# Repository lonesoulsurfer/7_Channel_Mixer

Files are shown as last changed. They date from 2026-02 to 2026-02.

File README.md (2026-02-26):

RHIM2508

SITY5105

YouTube - https://youtu.be/h-TxdCl6BcE

Instructables - https://www.instructables.com/7-Channel-Mixer-a-4-Channel-Option/

Here you can find everything you need to make your own 7 Channel Mixer.  This is based on Syntherjacks awesome little 4sum mixer which you can find a link below to.  My modular synth runs off 9/5V so this amp works perfectly for what I need.  You could also power it via traditional Eurorack style powering, you would just have to add a step down converter from the mixer to the 12V power source.

I have also included a Eurorack 4 channel version as well which will fit perfectly into any Eurorack.

https://syntherjack.net/portable-audio-mixer/

7 Channel Mixer - Circuit Explanation

This is a passive-input, op-amp buffered audio mixer built around an NE5532N dual op-amp. 

Here's how it works from input to output:

Input Stage (7 Channels)

* Each of the 7 channels (IN_1 through IN_7) follows the same structure. A 3-pin connector feeds into a 100K potentiometer (VOL_1 through VOL_7) which acts as the individual channel volume control. The wiper of each pot    connects through a 47K resistor to a common summing node. The 47K resistors serve as summing/isolation resistors — they prevent channels from loading each other and set the gain relationship between channels.

Summing & First Op-Amp Stage (IC1A)

* All 7 channel signals meet at the summing node, which connects through a 10µF coupling capacitor (blocking any DC offset) into the non-inverting (+) input of IC1A (the first half of the NE5532N). IC1A is configured as a unity-gain buffer with a 47K feedback resistor, providing a low-impedance version of the mixed signal. VREF is applied to bias the op-amp at the virtual mid-rail since this is a single-supply design.

Second Op-Amp Stage (IC1B) + Master Level

* The output of IC1A feeds into IC1B (the second half of the NE5532N). A 100K master LEVEL potentiometer in the feedback path of IC1B controls the overall output gain/volume. This gives you master level control over the entire mix.

Output Stage

* The output of IC1B passes through another 10µF coupling capacitor (again blocking DC) into an output volume pot and then to the OUT_1 connector.

Power Supply

* The circuit runs off a single +9V supply (PWR_9V connector). A BAT43 Schottky diode provides reverse polarity protection. Two 100µF filter capacitors smooth the supply rail. A resistor divider made of two 47K resistors creates a VREF mid-rail reference (~4.5V), which biases the op-amp stages so they can handle AC audio signals on a single supply. A LED with current-limiting resistor provides a power indicator.

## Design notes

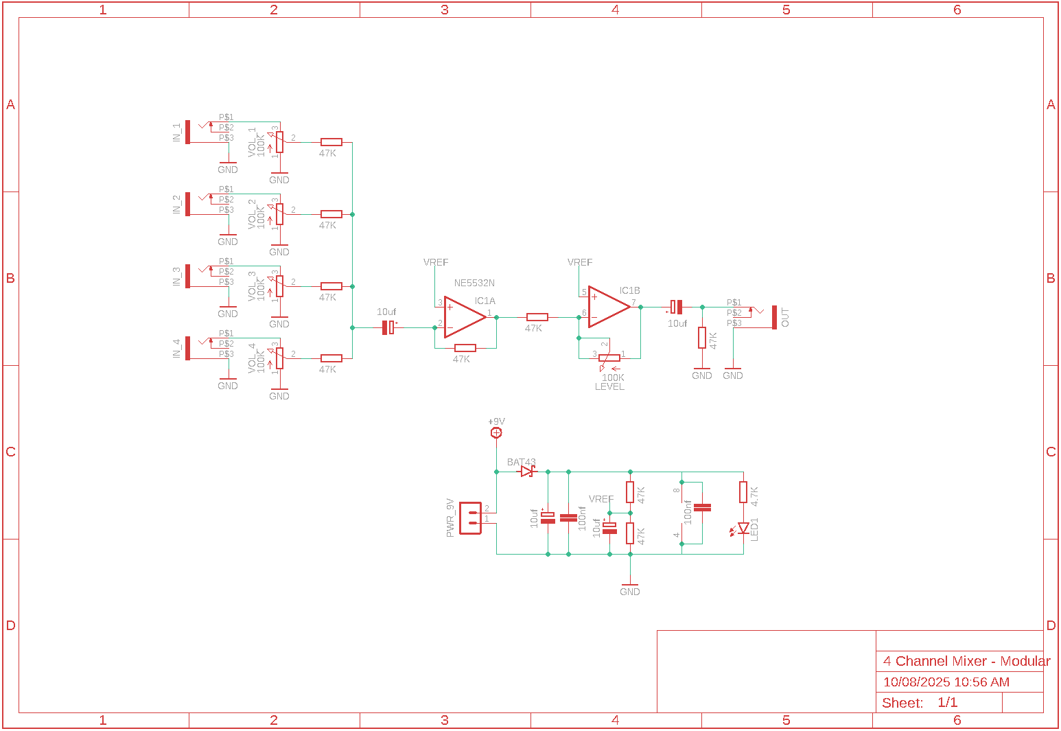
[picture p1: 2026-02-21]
Schematics/4 Channel Mixer - Schematic.png

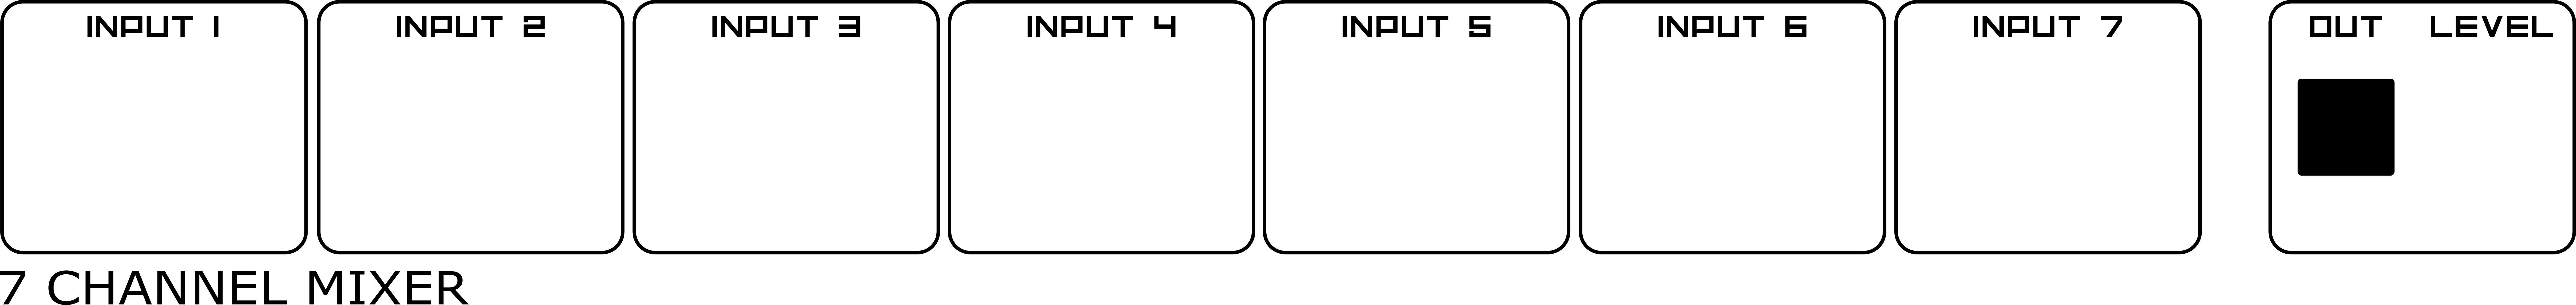
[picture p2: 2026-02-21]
Front_Panel_Design/7_Channel_Mixer_Front_Panel/7 Channel Mixer - Front Panel.png

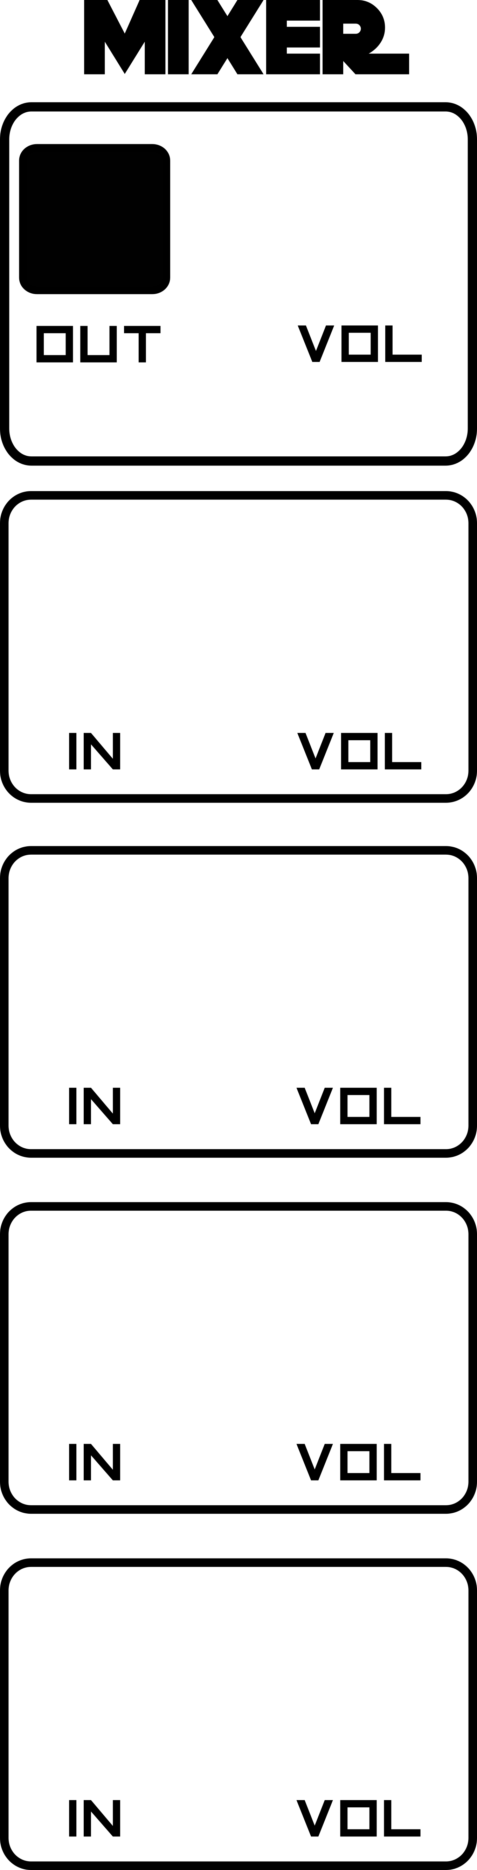
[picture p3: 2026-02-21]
Front_Panel_Design/4_Channel_Mixer_Front_Panel/Front Panel.png

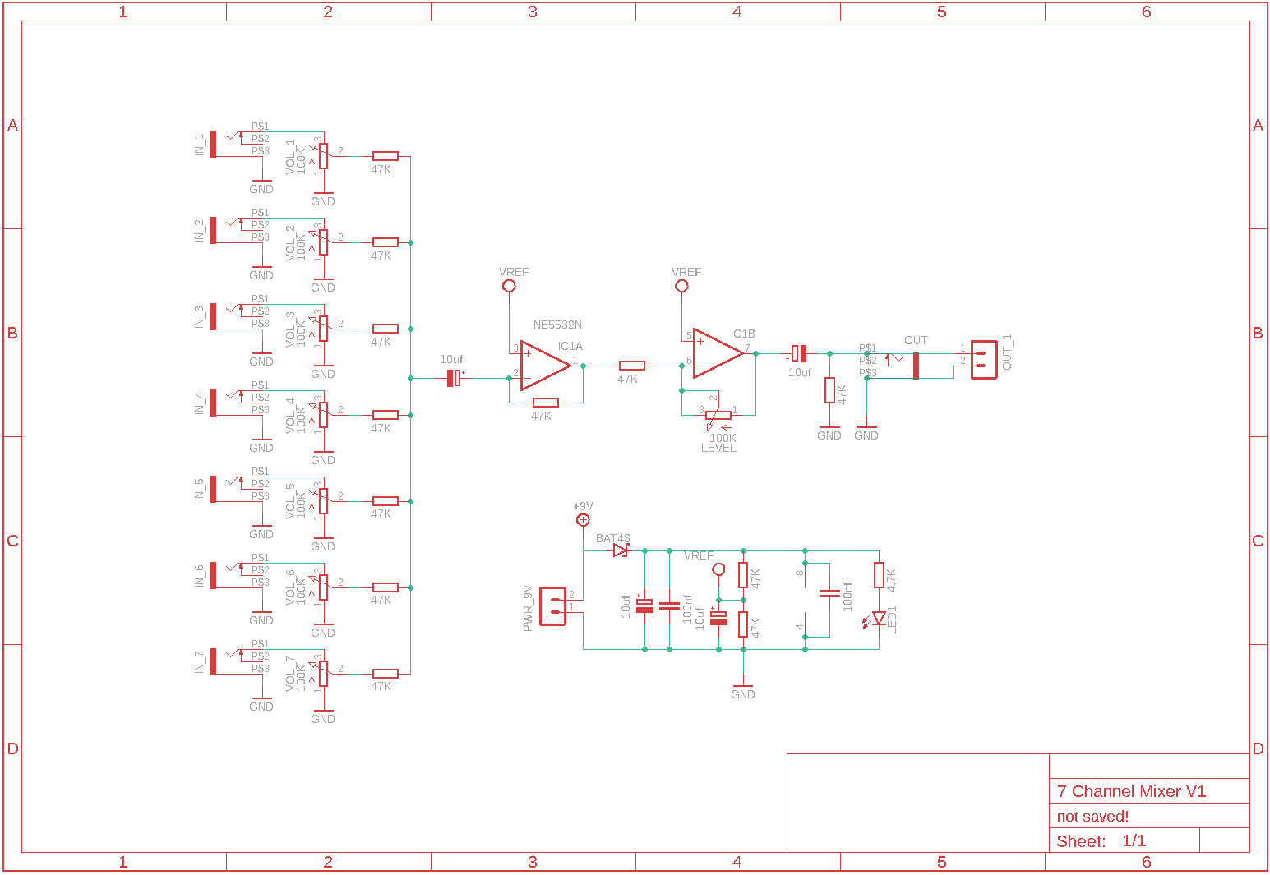
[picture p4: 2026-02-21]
Schematics/7 Channel Mixer - Schematic.png

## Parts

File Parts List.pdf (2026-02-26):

Part | Value | Type | Qty | Link | Image | Notes
Capacitor | 10uf 100nf | electrolytic Polypropylene | 4 2 | Link (https://www.aliexpress.com/w/wholesale-capacitor-10uf--High-frequency-l.html) Link (https://www.aliexpress.com/w/wholesale-100nf-polyester-capacitor.html)
Diode | | Bat43 | 1 | Link (https://www.aliexpress.com/w/wholesale-bat-43.html?spm=a2g0o.productlist.search.0)
IC | | NE5532N | 1 | Link (https://www.aliexpress.com/w/wholesale-NE5532N.html?spm=a2g0o.productlist.search.0)
Jack Socket | | PCB Mount - PJ301M | 8 | Link | | 5 pcs for 4 channel
LED | | 3mm (any colour you want) | 1 | Link (https://www.aliexpress.com/w/wholesale-3mm-led.html?spm=a2g0o.productlist.search.0)
Potentiometer | 100K | vertical | 8 | Link (https://www.aliexpress.com/w/wholesale-100k-potentiometer-verticle.html) | | 5 pcs for 4 channel
Resistors | 47K 4.7K | Metal film 1% | 12 1 | Link (https://www.aliexpress.com/w/wholesale-resistor-47K.html?spm=a2g0o.productlist.search.0)
JST Connector Potentiometer Knobs | | 2 pin - Male 2.0 | 1 8 | Link (https://www.aliexpress.com/w/wholesale-jst-2.0-connector.html?spm=a2g0o.productlist.search.0) Link (https://www.aliexpress.com/w/wholesale-potentiometer-knobs.html)

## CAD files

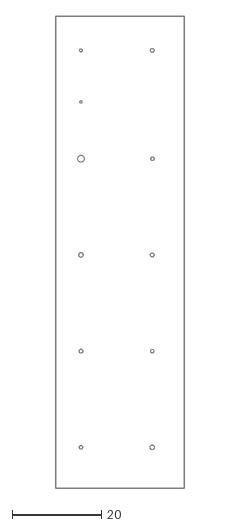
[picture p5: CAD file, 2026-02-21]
Front_Panel_Design/4_Channel_Mixer_Front_Panel/4 Channel Mixer - PCB.dxf
28.8 x 105.7

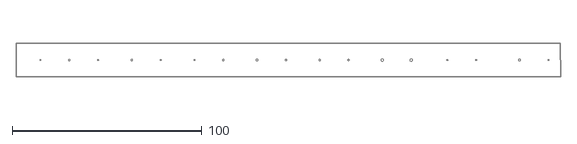
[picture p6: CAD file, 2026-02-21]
Front_Panel_Design/7_Channel_Mixer_Front_Panel/7 Channel Mixer PCB.dxf
287.0 x 17.6

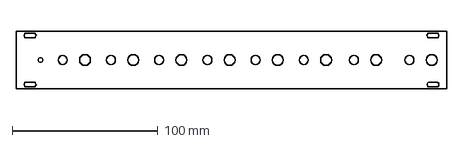
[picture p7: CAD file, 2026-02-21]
Front_Panel_Design/7_Channel_Mixer_Front_Panel/7 Channel Mixer Fusion.dxf
295.0 x 39.7 mm

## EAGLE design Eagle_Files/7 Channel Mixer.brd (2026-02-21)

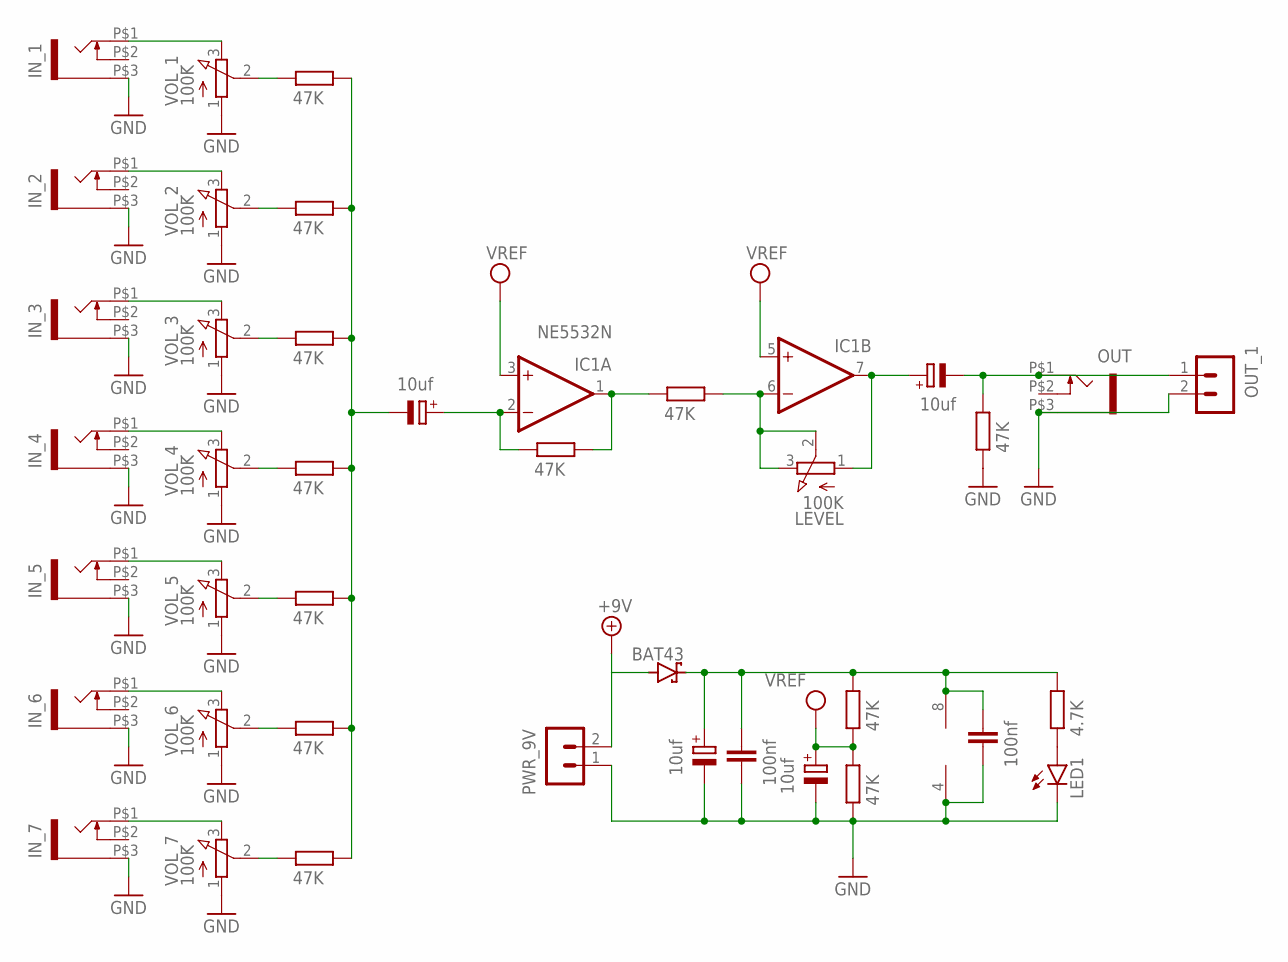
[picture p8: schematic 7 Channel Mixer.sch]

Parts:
C1, C2, C3, C4: 10uf; E2,5-6E
C5, C6: 100nf; C050-024X044
D4: BAT43; DO35-10
IC1: NE5532N; DIL08
IN_1, IN_2, IN_3, IN_4, IN_5, IN_6, IN_7: WQP-PJ301M-12_JACK
LED1: LED3MM
LEVEL: 100K; EVUFXM
OUT: WQP-PJ301M-12_JACK
OUT_1: B2B-PH-K-S
PWR_9V: B2B-PH-K-S
R1, R2, R3, R4, R5, R6, R7, R8, R9, R10, R11, R13: 47K; 0204/7
R12: 4.7K; 0204/7
VOL_1, VOL_2, VOL_3, VOL_4, VOL_5, VOL_6, VOL_7: 100K; EVUFXM

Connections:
+9V: D4.A, PWR_9V.2
GND: C3.-, C4.-, C5.1, C6.1, IC1.4 (V-), IN_1.P$3 (1), IN_2.P$3 (1), IN_3.P$3 (1), IN_4.P$3 (1), IN_5.P$3 (1), IN_6.P$3 (1), IN_7.P$3 (1), LED1.K (C), OUT.P$3 (1), OUT_1.2, PWR_9V.1, R9.2, R11.2, VOL_1.1 (A), VOL_2.1 (A), VOL_3.1 (A), VOL_4.1 (A), VOL_5.1 (A), VOL_6.1 (A), VOL_7.1 (A)
unnamed: IN_7.P$1 (2), VOL_7.3 (E)
unnamed: R1.2, VOL_2.2 (S)
unnamed: IN_5.P$1 (2), VOL_5.3 (E)
unnamed: R2.2, VOL_3.2 (S)
unnamed: IN_6.P$1 (2), VOL_6.3 (E)
unnamed: R3.2, VOL_4.2 (S)
unnamed: IN_3.P$1 (2), VOL_3.3 (E)
unnamed: R5.2, VOL_1.2 (S)
unnamed: R4.2, VOL_5.2 (S)
unnamed: IN_4.P$1 (2), VOL_4.3 (E)
unnamed: R6.2, VOL_6.2 (S)
unnamed: C1.-, R1.1, R2.1, R3.1, R4.1, R5.1, R6.1, R13.1
unnamed: C2.-, OUT.P$1 (2), OUT_1.1, R9.1
unnamed: C1.+, IC1.2 (-IN), R7.2
unnamed: IN_2.P$1 (2), VOL_2.3 (E)
unnamed: IC1.1 (OUT), R7.1, R8.2
unnamed: IC1.6 (-IN), LEVEL.2 (S), LEVEL.3 (E), R8.1
unnamed: C2.+, IC1.7 (OUT), LEVEL.1 (A)
unnamed: LED1.A, R12.2
unnamed: C4.+, C5.2, C6.2, D4.C, IC1.8 (V+), R10.1, R12.1
unnamed: IN_1.P$1 (2), VOL_1.3 (E)
unnamed: R13.2, VOL_7.2 (S)
VCC: C3.+, IC1.3 (+IN), IC1.5 (+IN), R10.2, R11.1

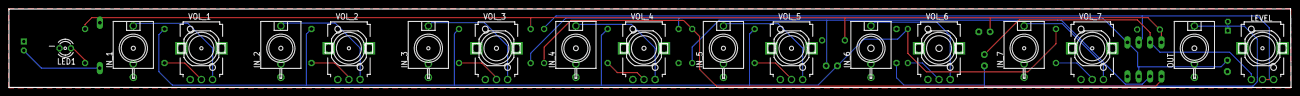
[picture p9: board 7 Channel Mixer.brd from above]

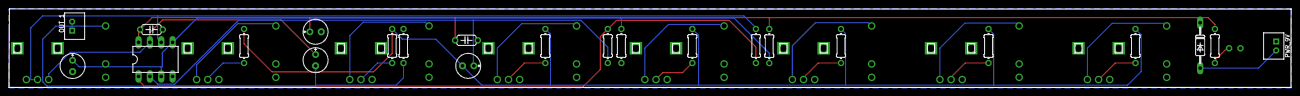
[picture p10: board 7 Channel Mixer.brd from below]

Board: 2 copper layers, 287.0 x 17.6 mm, 40 parts (23 on the bottom side), 25 nets.

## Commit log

2026-02-21 Add circuit explanation for 7 Channel Mixer
    Added detailed explanation of the 7 Channel Mixer circuit, including input stages, op-amp configurations, and power supply details.
2026-02-21 Format input stage and circuit description with bullet points
    Updated README.md to use bullet points for clarity.
